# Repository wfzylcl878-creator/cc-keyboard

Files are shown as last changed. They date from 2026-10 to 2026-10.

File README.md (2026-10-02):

# CC-Keyboard — 6 键蓝牙小键盘

方向键 + 回车 + ESC 的紧凑蓝牙小键盘。布局（两行 + 右侧竖跨 2u 回车）：

```
┌───┐      ┌───┐
│ESC│  ↑   │ ↵ │
└───┘      │   │
┌───┬───┬───┐   │
│ ← │ ↓ │ → │   │
└───┴───┴───┤   │
            └───┘
┌───────────┴────────────────────┐
│ 电池   [SuperMini 横放 USB←]  开关 │  ← 底部凸出区
└────────────────────────────────┘
```

主控 SuperMini nRF52840（排针插接可拆卸，躺平在底部凸出区、USB 朝左），ZMK 固件，热插拔轴座。

## 目录结构

```
cc-keyboard/
├── ergogen/config.yaml      # PCB 生成配置（改布局/接线就改它）
├── output/                  # 生成产物（可随时重新生成）
│   ├── pcbs/main.kicad_pcb  #   PCB（嘉立创打样直接上传）
│   ├── outlines/plate.dxf   #   定位板（1.5mm 激光切割/CNC）
│   ├── outlines/plate.svg   #   定位板 SVG（切片软件 3D 打印用，导入后厚度设 1.5mm）
│   └── outlines/board.dxf   #   外壳参考轮廓
├── zmk-config/              # ZMK 固件配置（push 到 GitHub 自动编译）
│   ├── build.yaml           #   编译矩阵（板卡 + shield）
│   ├── west.yml             #   west manifest（CI 用，须在此层级）
│   ├── cc_keyboard.keymap   #   键位（可加层）
│   └── boards/shields/cc_keyboard/   # shield（zephyr 标准目录）
│       ├── cc_keyboard.overlay       #   6 键直连扫描 + 引脚
│       └── cc_keyboard.conf
└── .github/workflows/build.yml  # 固件 CI（Actions 自动编译）
```

## 重新生成 PCB

```bash
cd cc-keyboard
npx ergogen ergogen/config.yaml -o output --svg
python3 tools/postprocess.py   # PCB 数字规整+排母孔转通孔、SVG 填充清理
```

## 制造 / BOM（约 ¥80）

| 部件 | 规格 | 数量 |
|---|---|---|
| PCB | `output/pcbs/main_clean.kicad_pcb` 导入嘉立创 EDA 布线后下单（见下） | 1 |
| 定位板 | `output/outlines/plate.dxf`，1.5mm | 1 |
| SuperMini nRF52840 | 带 UF2 bootloader | 1 |
| 排针/排母 | 2.54mm（SuperMini 焊排针，PCB 焊排母，8+1 孔） | 各 1 |
| MX 热插拔座 | 已在 PCB footprint 内 | 6（随 PCB） |
| 轴体 | 任意 MX | 6 |
| 键帽 | 1u×5 + 竖 2u 回车键帽 | 6 |
| 电池 | PH2.0 插头，401230 (150mAh) | 1 |
| 电源开关 | MSK-12C02 拨动（或不装、锡桥短接） | 1 |

## PCB 布线与下单

**Ergogen 只做布局、不布线**——`main.kicad_pcb` 里没有任何铜走线（EDA 里看到的连线全是飞线），直接打样回来不能工作。流程：

1. 嘉立创 EDA（pro.lceda.cn）→ 文件 → 导入 → KiCad PCB → 选 `output/pcbs/main_clean.kicad_pcb`（数字规整版，直传下单页可能解析失败）
2. 布线（全部才 13 个连接，一把过）：
   - 信号线宽 0.25mm，电源线（`BAT_*`）0.5mm
   - GND 用整板敷铜（放置 → 整块敷铜 → 网络 GND），省 6 条线
   - 懒人直接用 EDA 的自动布线，完成后肉眼检查
3. 设计规则检查（DRC）通过后一键下单

## 接线表（PCB 排母孔 → SuperMini）

排母双排（孔距 2.54mm、排距 15.24mm，SuperMini 每排 13 脚），SuperMini 横放 USB 朝左、元件面朝上插入：

| 孔 | 网络 | SuperMini 引脚（该排从 USB 端数第几脚） |
|---|---|---|
| 行A·1 | B- | B-（第 1 脚） |
| 行A·2 | ESC | P0.06（第 2 脚） |
| 行A·3 | ↑ | P0.08（第 3 脚） |
| 行A·4 | GND | GND（第 4 脚，第 5 脚是第二个 GND 不放孔） |
| 行A·6 | ← | P0.17（第 6 脚） |
| 行A·7 | ↓ | P0.20（第 7 脚） |
| 行A·8 | → | P0.22（第 8 脚） |
| 行A·9 | ⏎ | P0.24（第 9 脚） |
| 行B·1 | B+ | B+（第 1 脚，电池正经开关后接入） |

行B 只有一个孔——插反 180° 时对不上孔，天然防呆。SuperMini 上只需在对应 9 个脚焊排针，其余脚悬空。
电池接 PCB 凸出区左段的 JST PH 座（免焊）；BAT+ 串凸出区右段的电源开关后进 SuperMini。

## 固件（ZMK）

1. push 本仓库到 GitHub（`.github/workflows/build.yml` 已就位，push 即自动编译）
2. Actions 自动编译 → 构建产物页下载 `firmware.uf2`
3. SuperMini 双击 RST → 弹出 USB 磁盘 → 拖入 uf2 → 完成
4. 系统蓝牙配对 "CC-Keyboard" 即可使用

改键位：编辑 `zmk-config/cc_keyboard.keymap`（bindings 顺序对应排针 1-6），push 后重新下载 uf2。

## 焊接顺序

1. 热插拔轴座（贴片，先焊一个脚对位再焊其余）
2. 排母（8+1 孔）、JST 座、开关焊盘
3. SuperMini 焊 9 根排针（对应接线表的脚），插排母测试
4. 验证：插 USB → CHG 灯亮；按键在 ZMK 下生效（直接连手机蓝牙试）
4. 验证：插 USB → CHG 灯亮；按键在 ZMK 下生效（`zmk-kconfig test` 或直接连手机蓝牙试）

## 已知取舍

- 回车是**热插拔轴**竖跨 2u，键帽需 1×2 竖键帽；无卫星轴孔（2u 竖键无卫星轴可接受，边缘按压略晃，介意可后续 rev2 加 stab 孔）
- `where` 过滤器使用 `/regex/` 斜杠格式（Ergogen 的字符串 where 是全等匹配，不是正则）
- Ergogen 稀疏布局：列内 `rows` 不能删行，须对要删的键写 `skip: true`；且行按**声明顺序**自 y=0 向上堆叠，全局 `rows` 必须把 `bottom` 写在 `top` 前，否则行名与实际位置颠倒

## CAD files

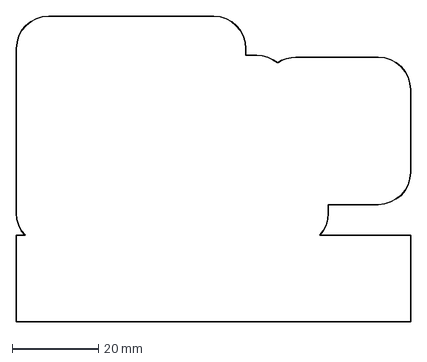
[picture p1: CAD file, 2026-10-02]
output/outlines/board.dxf
91.2 x 70.7 mm

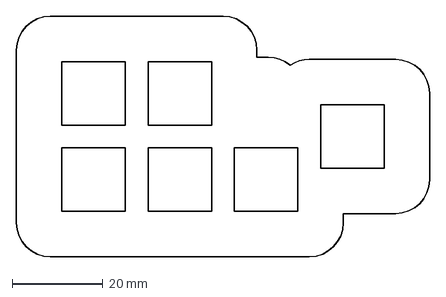
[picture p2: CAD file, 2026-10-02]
output/outlines/plate.dxf
91.2 x 53.1 mm

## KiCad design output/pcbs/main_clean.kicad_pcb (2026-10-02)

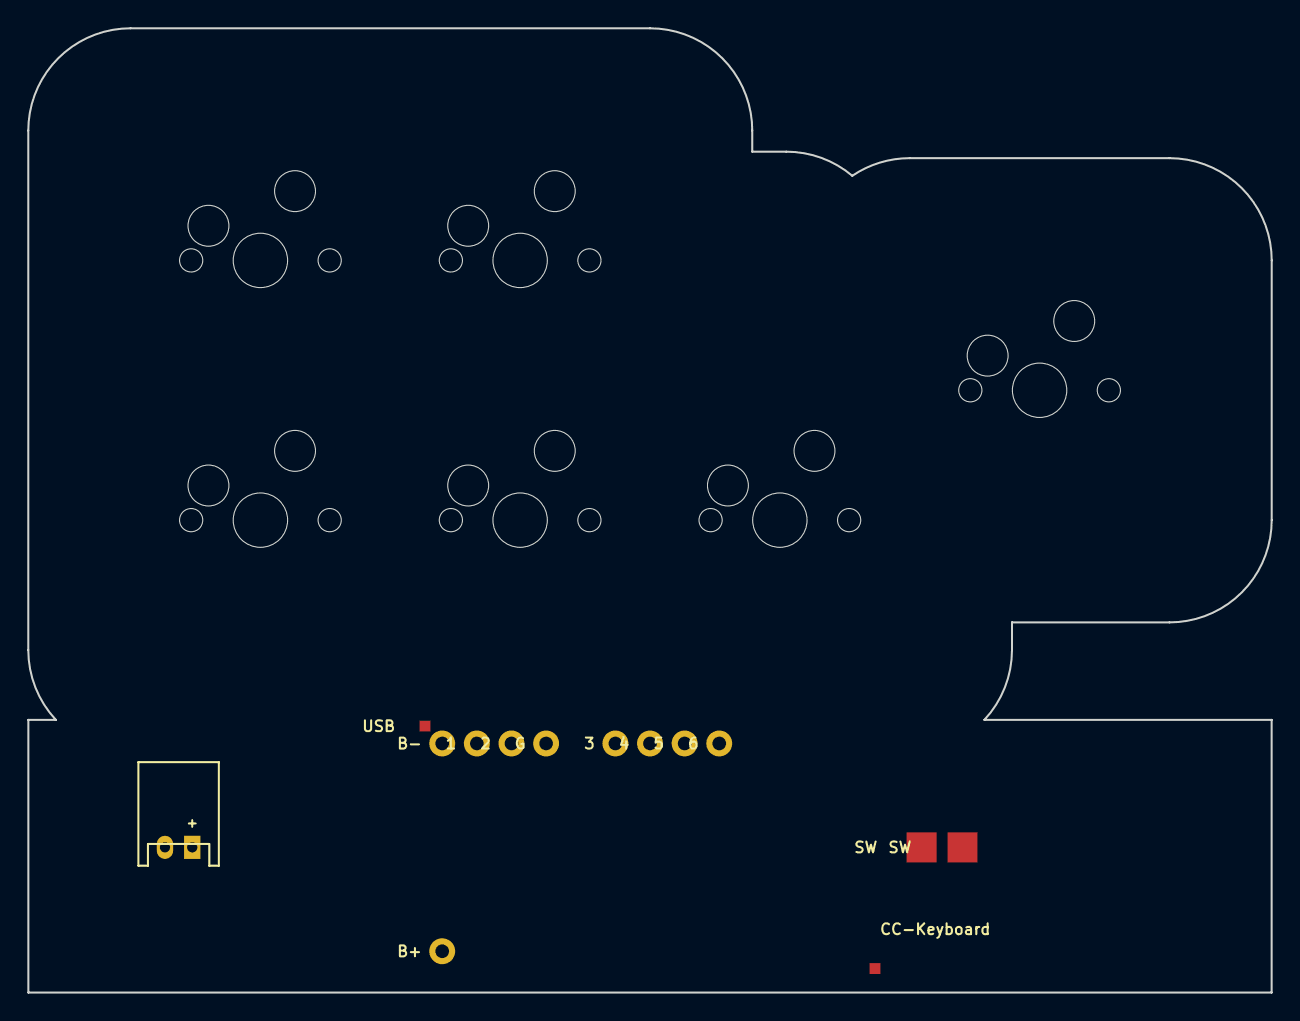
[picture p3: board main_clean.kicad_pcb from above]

Board: 2 copper layers, 91.2 x 70.7 mm, 21 parts (0 on the bottom side), 10 nets, no tracks yet.

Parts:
JST1: JST_PH_S2B-PH-K_02x2.0mm_Angled
PAD1, PAD2, PAD3, PAD4, PAD5, PAD6, PAD7, PAD8, PAD9, PAD10, PAD11, PAD12, PAD13, PAD14: SMDPad
S1, S2, S3, S4, S5, S6: MX

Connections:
BAT_MINUS: JST1.2, PAD1.1
BAT_PLUS: JST1.1, PAD12.1
BAT_SWITCHED: PAD9.1, PAD13.1
GND: PAD4.1, S1.1, S2.1, S3.1, S4.1, S5.1, S6.1
KEY_DOWN: PAD6.1, S4.2
KEY_ENTER: PAD8.1, S6.2
KEY_ESC: PAD2.1, S1.2
KEY_LEFT: PAD5.1, S2.2
KEY_RIGHT: PAD7.1, S5.2
KEY_UP: PAD3.1, S3.2

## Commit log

2026-10-01 初始提交：CC-Keyboard 6 键蓝牙小键盘
    Ergogen 生成 PCB/定位板 + ZMK 固件配置。
    CI 适配 monorepo：工作流移至仓库根、矩阵驱动构建，
    board 迁移到 nice_nano@2.0.0（原 nice_nano_v2）。
    [board.dxf, main.kicad_pcb, plate.dxf]
2026-10-01 修复 CI：west manifest 上移到 zmk-config/ 使 workspace 顶目录落在仓库根
    west init -l 以 manifest 目录的父目录为 workspace 顶目录，
    config_path 须为仓库根下的一级目录，否则 west update 找不到 workspace。
2026-10-01 修复 CI：shield 改用 zephyr 标准目录 boards/shields/
    新版 ZMK 中 zephyr 只认 BOARD_ROOT 下 boards/shields/<name>/<name>.overlay
    的结构，ZMK_CONFIG 根下的平铺 overlay 不再被识别；keymap 仍在 ZMK_CONFIG 根。
2026-10-01 修复 CI：补 shield 必需的 Kconfig.shield
    zephyr 发现 shield 靠 glob boards/shields/*/Kconfig.shield，
    缺此文件整个 shield 目录会被忽略（Invalid SHIELD）。
2026-10-01 修复固件：改用 zmk board variant（蓝牙此前未被编入）
    Zephyr 4.1 后 nice_nano@2.0.0 是裸 zephyr 板定义，CONFIG_BT=n，
    45KB 固件无 BLE；zmk variant 的 defconfig 才有 CONFIG_ZMK_BLE=y/CONFIG_ZMK_USB=y。
    同时 BT_DIS_MODEL 改为新符号 BT_DIS_MODEL_NUMBER_STR。
2026-10-02 修复布局与定位板：稀疏列用 skip、行序纠正、plate 补外框、输出 SVG
    - 原稀疏写法无效：列内 rows 不能删行，须 skip: true；
    行按声明顺序自 y=0 向上堆叠，bottom 须写在 top 前，
    否则行名与位置颠倒（此前 ESC/←、↑/↓ 键位互换，且多出 2 个孔位）
    - plate outline 此前只有轴孔没有板外形，补外框（键阵外扩 edge）+ subtract 挖孔
    - ergogen --svg 直接输出 plate.svg/board.svg（填充后处理），
    供 Bambu Studio 等切片软件导入 3D 打印定位板
    [board.dxf, main.kicad_pcb, plate.dxf]
2026-10-02 清理 SVG 描边，排除切片软件把 stroke 算进孔几何的可能
2026-10-02 修复电源开关网络：排针 B+ 改接 BAT_SWITCHED
    此前 SuperMini B+ 直连 BAT_PLUS，电池正极绕过开关，开关两焊盘
    中 SW OUT（BAT_SWITCHED）为孤立网络。现电路为电池+→SW IN→SW OUT→B+。
    README 增补布线与下单流程（ergogen 只布局不布线，须在嘉立创 EDA 布线）。
    [main_clean.kicad_pcb]
2026-10-02 PCB 加底部凸出区：SuperMini 躺平在板上（Pro Micro 兼容排母座）
    - 板形加全宽 20mm 凸出区（91.2×70.7mm），定位板仍只含键阵不冲突
    - 排母孔按 SuperMini/nice_nano_v2 pinout 摆双排（2.54 网格、排距 15.24），
    仅放用到的 9 孔，行B单孔天然防呆；pinout 经 kriscables 与 nice!nano v2
    两图交叉验证
    - 修复：原 pin1-9 用 pad footprint 是贴片焊盘插不了排母，
    postprocess.py 转为 1.0mm 通孔（顺带固化数字规整/SVG 清理）
    - 电池 JST、电源开关移入凸出区左右两段
    - 接线表/BOM/焊接顺序同步更新
    [board.dxf, main.kicad_pcb, main_clean.kicad_pcb]
2026-10-02 排母孔位对齐实物 SuperMini（用户提供丝印）
    实物每排 12 脚、排距 15.24：行A USB 端起 P0.06 P0.08 GND GND
    P0.17 P0.20 P0.22 P0.24 ...（首位不是 B-，与 kriscables 版不同）。
    原孔位整体错一格，已重排；该板无独立 B-，电池负极改并入 GND
    （BAT_MINUS 网络移除）。行B 单孔 B+ 防呆保留。
    [main.kicad_pcb, main_clean.kicad_pcb]
2026-10-02 排母孔位恢复 13×2 布局（用户确认每排 13 脚）
    13 孔网格下排 1 首位为 B-（kriscables/nice!nano_v2 两图一致，
    用户先前抄丝印漏了最边上的 B-）。B-/B+ 位于板端第一孔位，
    BAT_MINUS 网络恢复，电池负极接 B-。
    [main.kicad_pcb, main_clean.kicad_pcb]
